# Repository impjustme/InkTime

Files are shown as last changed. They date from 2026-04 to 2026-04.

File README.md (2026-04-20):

# InkTime

InkTime este un smartwatch open-source cu consum redus, construit in jurul microcontroller-ului nRF52840, cu ecran e-paper, alimentare din baterie Li-Po, incarcare prin USB-C, monitorizare baterie, IMU si feedback haptic. Platforma a fost proiectata pentru autonomie buna, dimensiuni compacte si integrare mecanica intr-o carcasa dedicata.

## Diagrama bloc

```
                                +----------------------+
                                |       USB-C          |
                                |   alimentare / USB   |
                                +----------+-----------+
                                           |
                                           v
                                +----------------------+
                                |   ESD Protection     |
                                |    USBLC6-2SC6Y      |
                                +----------+-----------+
                                           |
                                           v
                                +----------------------+
                                |  Li-Po Charger       |
                                |    BQ25180YBGR       |
                                +----+------------+----+
                                     |            |
                                     |            +--------------------+
                                     |                                 |
                                     v                                 v
                           +-------------------+             +-------------------+
                           |    Li-Po Battery  |             |   Fuel Gauge      |
                           |     LP502030      |<-- I2C ---> |    MAX17048       |
                           +---------+---------+             +-------------------+
                                     |
                                     v
                           +-------------------+
                           |  Buck-Boost DC/DC |
                           |    RT6160AWSC     |
                           +---------+---------+
                                     |
                                   3V3/VREG
                                     |
        +----------------------------+------------------------------+
        |                            |                              |
        v                            v                              v
+---------------+          +-------------------+          +-------------------+
|   nRF52840    |<--I2C--->|      BMA423       |<--I2C--->|     DRV2605       |
| BLE MCU       |          |       IMU         |          |   Haptic Driver   |
+-------+-------+          +-------------------+          +---------+---------+
        |                                                              |
        | SPI + GPIO                                                    v
        v                                                      +----------------+
+-------------------+                                          | Vibration Motor |
| 1.54" E-Paper     |                                          |    10 x 2.7 mm  |
| via FPC connector |                                          +----------------+
+-------------------+
        |
        +--> boost / gate drive pentru EPD:
             MOSFET-uri + diode Schottky + inductoare + condensatori
```

## BoM

| Componenta | Part number / Valoare  | Rol | Link JLC / sursa | Datasheet |
| --- | --- | --- | --- | --- |
| MCU | nRF52840 | microcontroller principal BLE | JLC Parts / external sourcing | [https://infocenter.nordicsemi.com/pdf/nRF52840_PS_v1.1.pdf](https://infocenter.nordicsemi.com/pdf/nRF52840_PS_v1.1.pdf) |
| PMIC charger | BQ25180YBGR | incarcare Li-Po prin USB-C | JLC Parts | [https://www.ti.com/lit/ds/symlink/bq25180.pdf](https://www.ti.com/lit/ds/symlink/bq25180.pdf) |
| DC/DC | RT6160AWSC | conversie VBAT -> 3V3/VREG | JLC Parts / external sourcing | [https://www.richtek.com/assets/product_file/RT6160A/DS6160A-05.pdf](https://www.richtek.com/assets/product_file/RT6160A/DS6160A-05.pdf) |
| Fuel gauge | MAX17048G+T10 | monitorizare baterie | JLC Parts / external sourcing | [https://www.analog.com/media/en/technical-documentation/data-sheets/max17048-max17049.pdf](https://www.analog.com/media/en/technical-documentation/data-sheets/max17048-max17049.pdf) |
| IMU | BMA423 | accelerometru triaxial | JLC Parts / external sourcing | [https://www.bosch-sensortec.com/products/motion-sensors/accelerometers/bma423/](https://www.bosch-sensortec.com/products/motion-sensors/accelerometers/bma423/) |
| Haptic driver | DRV2605YZFR | comanda motorului de vibratie | JLC Parts / external sourcing | [https://www.ti.com/lit/ds/symlink/drv2605.pdf](https://www.ti.com/lit/ds/symlink/drv2605.pdf) |
| ESD USB | USBLC6-2SC6Y | protectie ESD pentru USB | JLC Parts | [https://www.st.com/resource/en/datasheet/usblc6-2.pdf](https://www.st.com/resource/en/datasheet/usblc6-2.pdf) |
| Antena | 2450AT18B100E | antena 2.4 GHz | external sourcing | [https://www.johansontechnology.com/datasheets/antennas/2450AT18B100.pdf](https://www.johansontechnology.com/datasheets/antennas/2450AT18B100.pdf) |
| Conector debug | TC2030-IDC | SWD / debugging | external sourcing | [https://www.tag-connect.com/product/tc2030-idc](https://www.tag-connect.com/product/tc2030-idc) |
| Conector display | 503480-2400 | conector FPC pentru e-paper | external sourcing | [https://www.molex.com/en-us/products/part-detail/5034802400](https://www.molex.com/en-us/products/part-detail/5034802400) |
| USB-C | KH-TYPE-C-16P | alimentare si interfata USB | JLC Parts / external sourcing | |
| Cristal HF | 32 MHz, SMD 2016 | ceas principal MCU | JLC Parts / external sourcing | |
| Cristal LF | 32.768 kHz, SMD 3215 | RTC / low-power clock | JLC Parts / external sourcing | |
| MOSFET EPD | SI1308EDL-T1-GE3 | comanda in etajul e-paper | JLC Parts / external sourcing | [https://www.vishay.com/docs/68986/si1308edl.pdf](https://www.vishay.com/docs/68986/si1308edl.pdf) |
| MOSFET EPD | DMG2305UX-7 / echiv. | comanda in etajul e-paper | JLC Parts / external sourcing | [https://www.diodes.com/assets/Datasheets/DMG2305UX.pdf](https://www.diodes.com/assets/Datasheets/DMG2305UX.pdf) |
| Diode Schottky | MBR0530 | etaj boost / redresare EPD | JLC Parts / external sourcing | [https://www.onsemi.com/pdf/datasheet/mbr0530t1-d.pdf](https://www.onsemi.com/pdf/datasheet/mbr0530t1-d.pdf) |
| Inductor power | FTC252012SR47MBCA | inductor pentru RT6160 | JLC Parts | [https://jlcpcb.com/partdetail/6763488-FTC252012SR47MBCA/C5832368](https://jlcpcb.com/partdetail/6763488-FTC252012SR47MBCA/C5832368) |
| Inductor EPD | 68uH | inductor pentru boost EPD | JLC Parts / external sourcing | |
| Butoane | EVP-AKE31A | interfata utilizator | JLC Parts / external sourcing | |
| Baterie | LP502030, 3.7V, 250mAh | sursa principala de energie | external sourcing | |
| Display | 1.54" e-paper, 200x200 | afisaj principal | external sourcing | |
| Shaker | 10 x 2.7 mm | vibratie / feedback haptic | external sourcing | |
## Descriere hardware
1. Microcontroller principal

Sistemul este construit in jurul nRF52840, un microcontroller ARM Cortex-M4F cu BLE 5.x, suficient de performant pentru gestionarea afisajului e-paper, a senzorilor, a starii de baterie si a interfetei de utilizator.Pe partea de clock sunt folosite doua surse:

-un cristal de 32 MHz pentru clock-ul principal.

-un cristal de 32.768 kHz pentru RTC si scenarii low-power.

2. Alimentare si management energetic

Arhitectura de alimentare este impartita in trei blocuri.

BQ25180YBGR

Gestioneaza incarcarea bateriei Li-Po din USB-C. Intrarea de 5 V vine din VBUS, iar iesirea este conectata la bateria de o celula. Acest circuit este configurabil si monitorizabil, iar pinul de interrupt este dus catre MCU.

MAX17048

Monitorizeaza tensiunea si starea bateriei. Acesta comunica pe I2C cu microcontrollerul si expune un semnal de alerta pentru praguri critice sau schimbari de stare.

RT6160AWSC

Converteaza tensiunea bateriei intr-o alimentare stabila pentru sistemul digital. Acesta este blocul care alimenteaza rail-urile de lucru ale placii si perifericele sale.

In proiect, bateria nu este conectata printr-un conector JST clasic, ci direct la doua test pad-uri dedicate de pe PCB, una pentru VBAT si una pentru GND, pentru economie de spatiu.

3. Afisaj

Afisajul utilizat este un e-paper de 1.54", conectat printr-un conector FPC. Comunicatia cu MCU se face in principal prin SPI, iar pentru control sunt folosite si semnale GPIO dedicate:

CS

DC

RST

BUSY

Deoarece e-paper-ul necesita tensiuni si secvente specifice, exista un etaj discret dedicat pentru generarea si comutarea semnalelor de alimentare ale panelului, construit cu:

MOSFET-uri

diode Schottky

inductoare

condensatori de filtrare si bootstrap

4. IMU

BMA423 este accelerometrul triaxial folosit pentru detectie de miscare, pasi, gesturi si evenimente de trezire. Comunicatia se face pe I2C, iar semnalele de intrerupere sunt aduse pe GPIO-uri separate ale MCU-ului pentru reactii rapide si trezire din moduri low-power.

5. Feedback haptic

DRV2605 comanda un motor de vibratie compact. Comunicatia cu MCU se face pe I2C, iar activarea poate fi controlata si printr-un semnal GPIO dedicat. Acest bloc ofera feedback tactil pentru navigare, notificari si interactiuni de baza.

6. USB-C si protectie

Interfata USB-C este folosita pentru alimentare si, optional, interfata USB a microcontrollerului. Liniile sensibile sunt protejate cu USBLC6-2SC6Y. Liniile CC sunt terminate corespunzator pentru a permite functionarea corecta ca device.

7. RF si antena

Conectivitatea radio este realizata prin antena chip 2.4 GHz si o retea de matching RF. Antena este pozitionata la marginea PCB-ului, iar sub ea exista zona de keepout fara trasee si fara plan de masa, pentru a nu degrada performanta RF.

## Pini folositi

| Pin nRF52840  | Semnal | Destinatie | Motiv |
| --- | --- | --- | --- |
| P0.00 / XL1 | XL1 | cristal 32.768 kHz | clock low-power / RTC |
| P0.01 / XL2 | XL2 | cristal 32.768 kHz | clock low-power / RTC |
| P0.04 | IMU_INT1 | BMA423 | intrerupere senzor |
| P0.05 | IMU_INT2 | BMA423 | intrerupere senzor |
| P0.06 | EPD_CS | e-paper | selectie SPI display |
| P0.07 | EPD_DC | e-paper | selectie data/comanda |
| P0.08 | EPD_RST | e-paper | reset display |
| P0.09 | PMIC_INT | BQ25180 | interrupt charger / PMIC |
| P0.11 | SPI_SCK | e-paper | clock SPI |
| P0.12 | SPI_MOSI | e-paper | date SPI |
| P0.13 | EPD_BUSY | e-paper | busy status display |
| P0.14 | I2C_SCL | BMA423 / DRV2605 / MAX17048 / BQ25180 / RT6160 | magistrala I2C comuna |
| P0.15 | I2C_SDA | BMA423 / DRV2605 / MAX17048 / BQ25180 / RT6160 | magistrala I2C comuna |
| P0.18 / RESET | RESET | sistem | reset hardware |
| P0.19 | HAPTIC_EN | DRV2605 | enable local pentru blocul haptic |
| P0.26 | SW_UP | buton | input utilizator |
| P0.27 | SW_DN | buton | input utilizator |
| P1.00 | SW_ENT | buton | input utilizator |
| P1.01 | ALERT | MAX17048 | alerta fuel gauge |
| P1.09 | SWO | debug | trace / debugging |
| XC1 / XC2 | 32 MHz crystal | clock principal | stabilitate si RF |
| ANT | RF | antena + matching | transmisie radio BLE |
| SWDIO | debug | TC2030-IDC | programare / debug |
| SWDCLK | debug | TC2030-IDC | programare / debug |
| VBUS | alimentare USB | USB-C | intrare 5 V |
| D+ / D- | USB data | USB-C prin protectie ESD | interfata USB |

## PCB

Layer stack

Structura folosita:

Top - componente, rutare semnale, poligoane GND locale

Route2 - plan principal de masa / referinta

Route15 - rutare interna suplimentara pentru semnale si distributie

Bottom - rutare suplimentara si zone GND

## Design log

In procesul de layout au fost acceptate:

1. SMD - via / pin overlap

In zone foarte dense, in special langa capsule mici si in fanout-ul unor componente fine-pitch, anumite vias au fost plasate direct pe pini ai componentelor.

3. Copper width warnings

Pe rail-urile de putere s-a urmarit 0.3 mm acolo unde spatiul permite. In fanout-uri foarte scurte, imediat la iesirea din pini foarte mici sau intre componente apropiate, au ramas segmente locale mai inguste. Distributia principala de putere a fost mentinuta lata, iar exceptiile sunt limitate la zonele de iesire.

4. Board outline / edge related warnings

Elementele de interfata ale produsului, in special anumite butoane si zona conectorului, au fost aliniate mecanic cu produsul final. Acolo unde apar avertizari de proximitate fata de conturul placii, acestea au fost evaluate din punct de vedere mecanic si acceptate daca nu afecteaza functionalitatea.

5. Unghiuri drepte locale
   
Desi rutarea a fost facuta preponderent fara colturi de 90 de grade, au ramas cateva unghiuri drepte locale in zone foarte aglomerate. Acestea au fost mentinute doar acolo unde alternativele cresteau numarul de vias sau complicau excesiv rutarea.

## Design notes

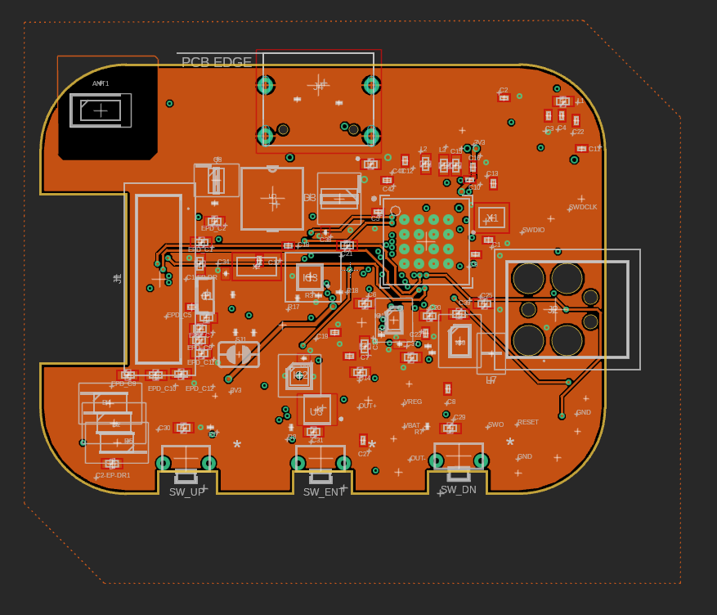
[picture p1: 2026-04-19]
Images/r15.png

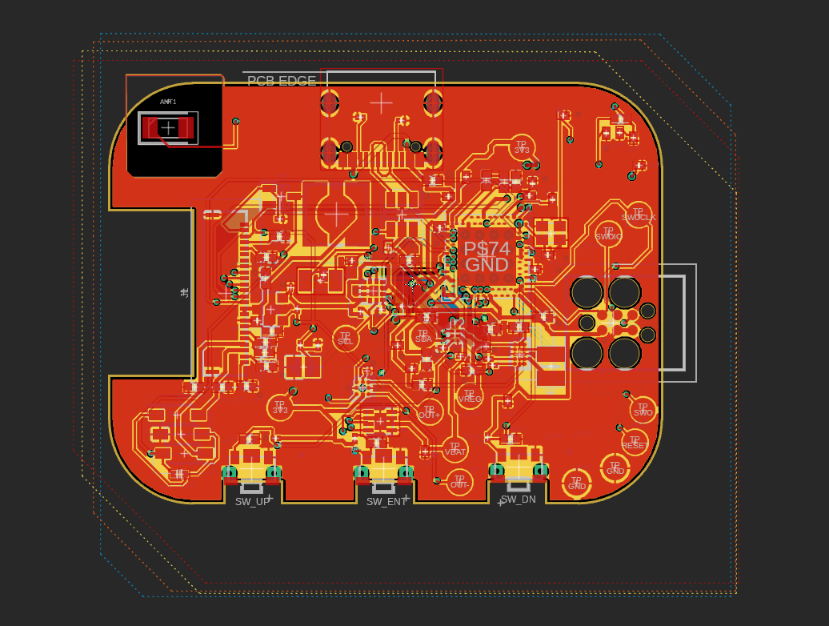
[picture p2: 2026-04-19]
Images/all_layers.png

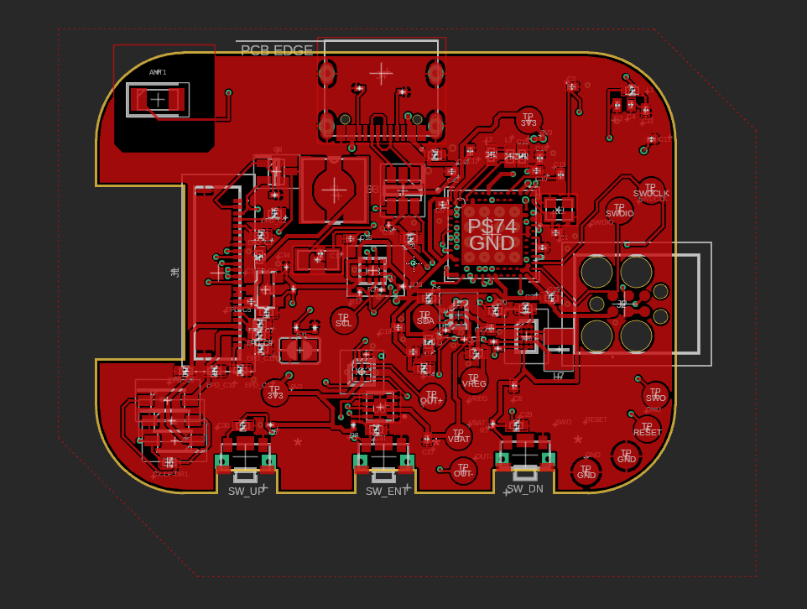
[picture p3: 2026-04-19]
Images/top.png

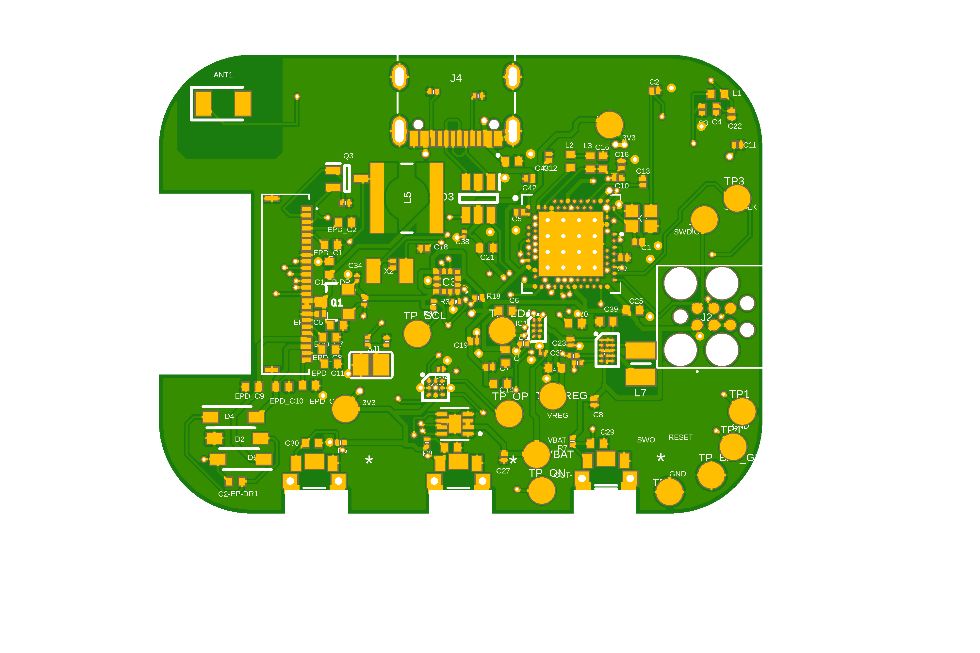
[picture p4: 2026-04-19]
Images/InkTime_cam_preview.png

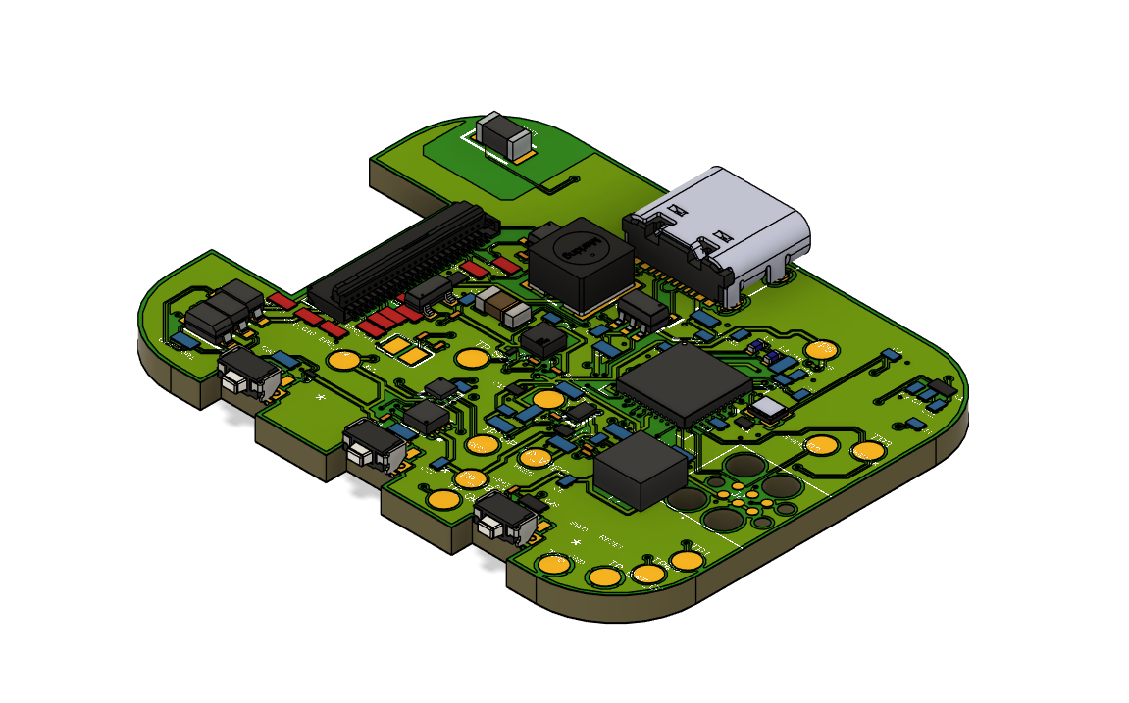
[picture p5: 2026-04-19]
Images/side_3D.png

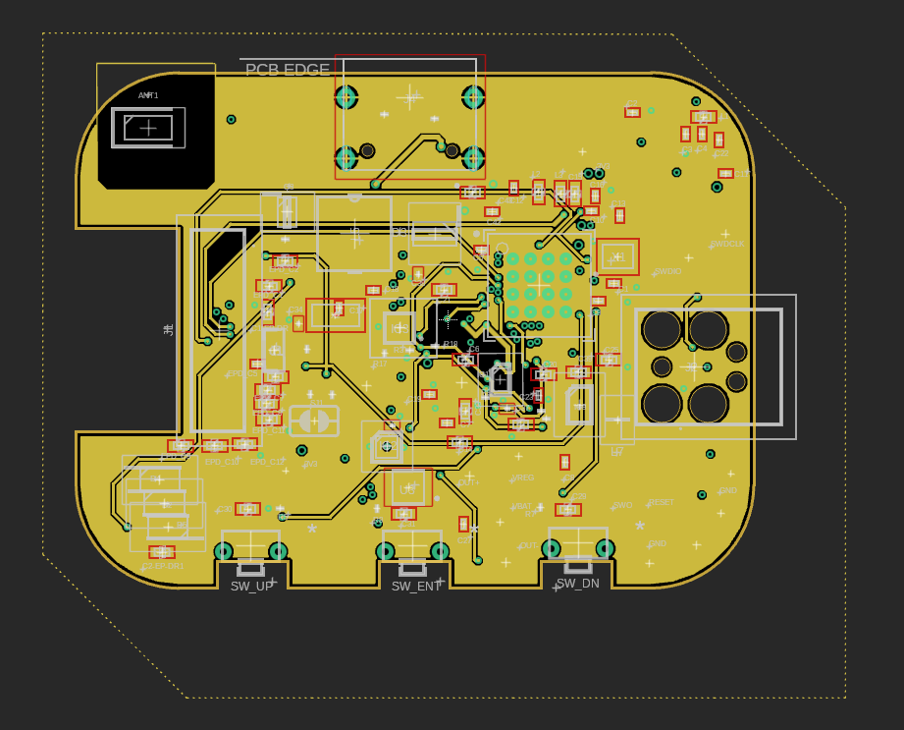
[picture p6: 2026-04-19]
Images/r2.png

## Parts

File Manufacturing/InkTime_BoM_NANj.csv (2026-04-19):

Qty | Value | Device | Package | Parts | Description | ARROW_PART_NUMBER | ARROW_PRICE-STOCK | AVAILABILITY | CHECK_PRICES | COPYRIGHT | DESCRIPTION | DIGI-KEY_PART_NUMBER_1 | DIGI-KEY_PART_NUMBER_2 | DIGI-KEY_PART_NUMBER_3 | HEIGHT | JLCPCB | MANUFACTURER_NAME | MANUFACTURER_PART_NUMBER | MF | MFR_NAME | MOUSER_PART_NUMBER | MOUSER_PRICE-STOCK | MP | PACKAGE | POPULARITY | PRICE | PROD_ID | PURCHASE-URL | SNAPEDA_LINK | TP_SIGNAL_NAME | VALUE
1 |  | ESP32_C6_LIBRARY_7_JUMPER_SJ | ESP32_C6_LIBRARY_7_JUMPER_SJ | SJ1 | SMD solder JUMPER |  |  |  |  |  |  |  |  |  |  |  |  |  |  |  |  |  |  |  | 3
2 |  | NORDIC_NRF_3_CAPACITOR_0201_L | NORDIC_NRF_3_RESC0201_L | C10, C13 | Generic chip capacitor
1 | 0.1uF | GRM011R60J152KE01L_2_GRM011R60J152KE01L | GRM011R60J152KE01L_2_CAPC0201X13N | C34 | Check availability |  |  | In Stock | https://www.snapeda.com/parts/GRM011R60J152KE01L/Murata/view-part/?ref=eda |  | SMD Capacitor X5R(EIA) with Capacitance: 1500pF Tol. 10%. Rated Voltage: 6.3Vdc |  |  |  |  |  |  |  | Murata |  |  |  | GRM011R60J152KE01L | 0201 Murata |  | None |  |  | https://www.snapeda.com/parts/GRM011R60J152KE01L/Murata/view-part/?ref=snap
3 | 0.1uF | NORDIC_NRF_3_CAPACITOR_0201_L | NORDIC_NRF_3_RESC0201_L | C23, C27, C42 | Generic chip capacitor
1 | 0.1uF/50V | NORDIC_NRF_3_CAPACITOR_0201_L | NORDIC_NRF_3_RESC0201_L | EPD_C5 | Generic chip capacitor
1 | 0.47 | CPF0201D7K68C1_CPF0201D7K68C1 | CPF0201D7K68C1_0201 | R1_EP_DR | 7.68k 0201 Thin Film Surface Mount Fixed Resistor +/-0.5% 0.031W CPF0201D7K68C1
1 | 1.0µF | NORDIC_NRF_3_CAPACITOR_0402_L | NORDIC_NRF_3_RESC0402_L | C15 | Generic chip capacitor
5 | 100nF | NORDIC_NRF_3_CAPACITOR_0201_L | NORDIC_NRF_3_RESC0201_L | C5, C7, C8, C12, C19 | Generic chip capacitor
1 | 100pF | NORDIC_NRF_3_CAPACITOR_0201_L | NORDIC_NRF_3_RESC0201_L | C11 | Generic chip capacitor
3 | 10K | CPF0201D7K68C1_CPF0201D7K68C1 | CPF0201D7K68C1_0201 | R2_EP_DR, R9, R_PWR_EPD | 7.68k 0201 Thin Film Surface Mount Fixed Resistor +/-0.5% 0.031W CPF0201D7K68C1
3 | 10k | CPF0201D7K68C1_CPF0201D7K68C1 | CPF0201D7K68C1_0201 | R5, R7, R8 | 7.68k 0201 Thin Film Surface Mount Fixed Resistor +/-0.5% 0.031W CPF0201D7K68C1
3 | 10uF | NORDIC_NRF_3_CAPACITOR_0402_L | NORDIC_NRF_3_RESC0402_L | C1-EP-DR, C24, C39 | Generic chip capacitor
1 | 10µH | NORDIC_NRF_2_INDUCTOR_0402_L | NORDIC_NRF_2_RESC0402_L | L2 | Generic chip inductor
4 | 12pF | NORDIC_NRF_3_CAPACITOR_0201_L | NORDIC_NRF_3_RESC0201_L | C1, C2, C17, C18 | Generic chip capacitor
1 | 15nF | NORDIC_NRF_2_INDUCTOR_0402_L | NORDIC_NRF_2_RESC0402_L | L3 | Generic chip inductor
2 | 1pF | NORDIC_NRF_3_CAPACITOR_0201_L | NORDIC_NRF_3_RESC0201_L | C3, C4 | Generic chip capacitor
3 | 1uF | GRM011R60J152KE01L_2_GRM011R60J152KE01L | GRM011R60J152KE01L_2_CAPC0201X13N | C32, C37, C38 | Check availability |  |  | In Stock | https://www.snapeda.com/parts/GRM011R60J152KE01L/Murata/view-part/?ref=eda |  | SMD Capacitor X5R(EIA) with Capacitance: 1500pF Tol. 10%. Rated Voltage: 6.3Vdc |  |  |  |  |  |  |  | Murata |  |  |  | GRM011R60J152KE01L | 0201 Murata |  | None |  |  | https://www.snapeda.com/parts/GRM011R60J152KE01L/Murata/view-part/?ref=snap
3 | 1uF | NORDIC_NRF_3_CAPACITOR_0402_L | NORDIC_NRF_3_RESC0402_L | C29, C30, C31 | Generic chip capacitor
9 | 1uF/50V | NORDIC_NRF_3_CAPACITOR_0402_L | NORDIC_NRF_3_RESC0402_L | EPD_C1, EPD_C2, EPD_C6, EPD_C7, EPD_C8, EPD_C9, EPD_C10, EPD_C11, EPD_C12 | Generic chip capacitor
1 | 2.2 | CPF0201D7K68C1_CPF0201D7K68C1 | CPF0201D7K68C1_0201 | R_TYPE_SEL | 7.68k 0201 Thin Film Surface Mount Fixed Resistor +/-0.5% 0.031W CPF0201D7K68C1
2 | 2025-10-22_07-23-44_LIBRARY_EVP-AKE31ASW_EVP-AKE31A_PAN | 2025-10-22_07-23-44_LIBRARY_EVP-AKE31ASW_EVP-AKE31A_PAN | 2025-10-22_07-23-44_LIBRARY_SW_EVP-AKE31A_PAN | SW_DN, SW_UP |  |  |  |  |  | Copyright (C) 2025 Ultra Librarian. All rights reserved. |  | P123437TR-ND | P123437CT-ND | P123437DKR-ND |  |  | Panasonic | EVP-AKE31A
1 | 20V/4.2A/52mO/1.4W | ESP32_C6_LIBRARY_4_ESP32_WROVER_SPARKFUN-DISCRETESEMI_MOSFET_PCH-DMG2305UX-7 | ESP32_C6_LIBRARY_4_ESP32_C6_LIBRARY_4_ESP32_C6_LIBRARY_4_ESP32_C6_LIBRARY_4_ESP32_WROVER_SPARKFUN-DISCRETESEMI_SOT23-3 | Q1 | P-channel MOSFETs |  |  |  |  |  |  |  |  |  |  |  |  |  |  |  |  |  |  |  |  |  | TRAN-14388 |  |  |  | 20V/4.2A/52mO/1.4W
2 | 22uF | NORDIC_NRF_3_CAPACITOR_0402_L | NORDIC_NRF_3_RESC0402_L | C25, C33 | Generic chip capacitor
1 | 2450AT18B100E | 2450AT18B100E_2450AT18B100E | 2450AT18B100E_ANTC3216X140N | ANT1 | Antennas 2.45GHz ANTENNA | 2450AT18B100E | https://www.arrow.com/en/products/2450at18b100e/johanson-dielectrics?utm_currency=USD&region=nac |  |  |  | Antennas 2.45GHz ANTENNA |  |  |  | 1.4mm |  | JOHANSON TECHNOLOGY | 2450AT18B100E |  |  | 609-2450AT18B100E | https://www.mouser.co.uk/ProductDetail/Johanson-Technology/2450AT18B100E?qs=yCnrNFeXz%252Bh5MFsFIXGZGA%3D%3D
1 | 3.9nH | NORDIC_NRF_2_INDUCTOR_0402_L | NORDIC_NRF_2_RESC0402_L | L1 | Generic chip inductor
1 | 32.768kHz | NORDIC_NRF_1_XTAL_32KHZ | NORDIC_NRF_1_XTAL_3215_N | X2
1 | 32MHz | NORDIC_NRF_XTAL_32MHZ | NORDIC_NRF_BT-XTAL_2016_N | X1
2 | 3K3 | CPF0201D7K68C1_CPF0201D7K68C1 | CPF0201D7K68C1_0201 | R17, R18 | 7.68k 0201 Thin Film Surface Mount Fixed Resistor +/-0.5% 0.031W CPF0201D7K68C1
1 | 4.7uF | NORDIC_NRF_3_CAPACITOR_0402_L | NORDIC_NRF_3_RESC0402_L | C43 | Generic chip capacitor
1 | 4.7uF/25V | NORDIC_NRF_3_CAPACITOR_0402_L | NORDIC_NRF_3_RESC0402_L | C2-EP-DR1 | Generic chip capacitor
4 | 4.7µF | NORDIC_NRF_3_CAPACITOR_0402_L | NORDIC_NRF_3_RESC0402_L | C6, C14, C20, C21 | Generic chip capacitor
1 | 47nF | NORDIC_NRF_3_CAPACITOR_0201_L | NORDIC_NRF_3_RESC0201_L | C16 | Generic chip capacitor
1 | 503480-2400 | 503480-2400_503480-2400 | 503480-2400_5034802400 | J1 | FFC & FPC Connectors 0.5mm FPC RA SMT Dual Contact 24Ckt |  |  |  |  |  | FFC & FPC Connectors 0.5mm FPC RA SMT Dual Contact 24Ckt |  |  |  | 1.87mm |  | Molex | 503480-2400 |  |  | 538-503480-2400 | https://www.mouser.co.uk/ProductDetail/Molex/503480-2400?qs=OAhjpuo3Vu7efIoxFh9AOw%3D%3D
2 | 5K1 | ERA-1AEB3401C_CPF0201D7K68C1 | ERA-1AEB3401C_0201 | R1_USB, R2_USB | 7.68k 0201 Thin Film Surface Mount Fixed Resistor +/-0.5% 0.031W CPF0201D7K68C1
1 | 68uH | ESP32_C6_LIBRARY_2_744043680IND_4828-WE-TPC_WRE | ESP32_C6_LIBRARY_2_IND_4828-WE-TPC_WRE | L5 |  |  |  |  |  | Copyright (C) 2024 Ultra Librarian. All rights reserved. |  |  |  |  |  |  |  | 744043680 |  | Wurth Electronics
1 | 820pF | NORDIC_NRF_3_CAPACITOR_0201_L | NORDIC_NRF_3_RESC0201_L | C9 | Generic chip capacitor
1 | BMA423 | BMA423_BMA423 | BMA423_BMA423 | IC3 | Accelerometers Triaxial low-g 12bit Acceleration Sensor | BMA423 | https://www.arrow.com/en/products/bma423/bosch |  |  |  | Accelerometers Triaxial low-g 12bit Acceleration Sensor |  |  |  | 1mm |  | BOSCH | BMA423 |  |  | 262-BMA423 | https://www.mouser.co.uk/ProductDetail/Bosch-Sensortec/BMA423?qs=HXFqYaX1Q2xC%252BSgeGoX3mg%3D%3D
1 | BQ25180YBGR | BQ25180YBGR_BQ25180YBGR | BQ25180YBGR_BGA8C40P2X4_100X155X50 | IC1 | Charger IC Lithium Ion/Polymer, Lithium Iron Phosphate 8-DSBGA (1.6x1.1) | BQ25180YBGR | https://www.arrow.com/en/products/bq25180ybgr/texas-instruments?utm_currency=USD&region=nac |  |  |  | Charger IC Lithium Ion/Polymer | Lithium Iron Phosphate 8-DSBGA (1.6x1.1) |  |  |  | 0.5mm |  | Texas Instruments | BQ25180YBGR |  |  | 595-BQ25180YBGR | https://www.mouser.co.uk/ProductDetail/Texas-Instruments/BQ25180YBGR?qs=doiCPypUmgEWjAK%252BJAX6Tw%3D%3D
3 | CPF0201D7K68C1_CPF0201D7K68C1 | CPF0201D7K68C1_CPF0201D7K68C1 | CPF0201D7K68C1_0201 | R2, R3, R4 | 7.68k 0201 Thin Film Surface Mount Fixed Resistor +/-0.5% 0.031W CPF0201D7K68C1
1 | DRV2605YZFR | DRV2605YZFR_DRV2605YZFR | DRV2605YZFR_BGA9C50P3X3_144X144X62 | IC2 | Haptic Driver for ERM/LRA with Built-In Library and Smart Loop Architecture | DRV2605YZFR | https://www.arrow.com/en/products/drv2605yzfr/texas-instruments?region=nac |  |  |  | Haptic Driver for ERM/LRA with Built-In Library and Smart Loop Architecture |  |  |  | 0.625mm |  | Texas Instruments | DRV2605YZFR
1 | FTC252012SR47MBCA | MLP2016SR47MT0S1_FTC252012SR47MBCA | MLP2016SR47MT0S1_INDC2016X100N | L7 | SMD / SMT Inductors (Coils), L=0.47?H, L x W x T : |  |  |  |  |  | SMD / SMT Inductors (Coils) | L=0.47?H | L x W x T : |  |  |  | 1mm | https://jlcpcb.com/partdetail/6763488-FTC252012SR47MBCA/C5832368 | TDK | FTC252012SR47MBCA
14 | HECTOR_WATCH_1_TPTP20R | HECTOR_WATCH_1_TPTP20R | HECTOR_WATCH_1_TP20R | TP1, TP2, TP3, TP4, TP5, TP6, TP_3V3, TP_BAT_GND, TP_ON, TP_OP, TP_SCL, TP_SDA, TP_VBAT, TP_VREG | Test pad |  |  |  |  |  |  |  |  |  |  |  |  |  |  |  |  |  |  |  | 2
1 | KH-TYPE-C-16P | KH-TYPE-C-16P_KH-TYPE-C-16P | KH-TYPE-C-16P_KINGHELM_KH-TYPE-C-16P | J4 | Check availability |  |  | Not in stock | https://www.snapeda.com/parts/KH-TYPE-C-16P/Kinghelm/view-part/?ref=eda |  |  |  |  |  |  |  |  |  | kinghelm |  |  |  | KH-TYPE-C-16P | None |  | None |  |  | https://www.snapeda.com/parts/KH-TYPE-C-16P/Kinghelm/view-part/?ref=snap
1 | MAX17048G+T10 | ESP32_C6_LIBRARY_MAX17048G+T10 | ESP32_C6_LIBRARY_SON50P200X200X80-9N | U3 | Check availability |  |  | In Stock | https://www.snapeda.com/parts/MAX17048G+T10/Analog+Devices/view-part/?ref=eda |  | 3µA 1-Cell/2-Cell Fuel Gauge with ModelGauge |  |  |  |  |  |  |  | Analog Devices |  |  |  | MAX17048G+T10 | TDFN-8 Maxim |  | None |  | https://www.snapeda.com/api/url_track_click_mouser/?unipart_id=329239&manufacturer=Analog Devices&part_name=MAX17048G+T10&search_term=None | https://www.snapeda.com/parts/MAX17048G+T10/Analog+Devices/view-part/?ref=snap
3 | MBR0530 | ESP32_C6_LIBRARY_5_MBR0530 | ESP32_C6_LIBRARY_5_SOD3716X135N | D2, D4, D5 | ON SEMICONDUCTOR - MBR0530 - DIODE, SCHOTTKY, 0.5A, 30V, SOD-123 |  |  | In Stock | https://www.snapeda.com/parts/MBR0530/Onsemi/view-part/?ref=eda |  | Diode Schottky 30 V 500mA Surface Mount SOD-123 |  |  |  |  |  |  |  | ON Semiconductor |  |  |  | MBR0530 | SOD-123-2 ON Semiconductor |  | None |  | https://www.snapeda.com/api/url_track_click_mouser/?unipart_id=179458&manufacturer=ON Semiconductor&part_name=MBR0530&search_term=None | https://www.snapeda.com/parts/MBR0530/Onsemi/view-part/?ref=snap
1 | N.C. | NORDIC_NRF_3_CAPACITOR_0201_L | NORDIC_NRF_3_RESC0201_L | C22 | Generic chip capacitor
1 | NRF52840_QF | NORDIC_NRF_4_NRF52840_QF | NORDIC_NRF_4_AQFN50P700X700X85_HS-74N | U1 | nRF52840
1 | RT6160AWSC | RT6160AWSC_RT6160AWSC | RT6160AWSC_BGA15C40P3X5_140X230X60 | IC9 | Buck-Boost Regulator Positive Output Step-Up/Step-Down I2C DC-DC Controller IC 15-WL-CSP (BSC) (1.4x2.3) |  |  |  |  |  | Buck-Boost Regulator Positive Output Step-Up/Step-Down I2C DC-DC Controller IC 15-WL-CSP (BSC) (1.4x2.3) |  |  |  | 0.6mm |  | RICHTEK | RT6160AWSC |  |  | 835-RT6160AWSC | https://www.mouser.co.uk/ProductDetail/Richtek/RT6160AWSC?qs=amGC7iS6iy%2FLd9PSoixZXQ%3D%3D
1 | SI1308EDL-T1-GE3 | ESP32_C6_LIBRARY_6_SI1308EDL-T1-GE3 | ESP32_C6_LIBRARY_6_SOT65P210X110-3N | Q3 | MOSFET N-Ch 30V 1.5A TrenchFET SC70 Vishay Si1308EDL-T1-GE3 N-channel MOSFET Transistor, 1.5 A, 30 V, 3-Pin SC-70 |  |  | In Stock | https://www.snapeda.com/parts/SI1308EDL-T1-GE3/Vishay+Siliconix/view-part/?ref=eda |  | Si1308EDL-T1-GE3 N-channel MOSFET Transistor | 1.5 A | 30 V | 3-Pin SC-70 | Siliconix / Vishay SI1308EDL-T1-GE3 |  |  |  |  |  |  |  | Vishay Siliconix |  |  |  | SI1308EDL-T1-GE3 | SOT-323 Vishay Semiconductor |  | None |  | https://www.snapeda.com/api/url_track_click_mouser/?unipart_id=274603&manufacturer=Vishay Siliconix&part_name=SI1308EDL-T1-GE3&search_term=None
1 | SW_ENT | 2025-10-22_07-23-44_LIBRARY_EVP-AKE31ASW_EVP-AKE31A_PAN | 2025-10-22_07-23-44_LIBRARY_SW_EVP-AKE31A_PAN | SW_ENT |  |  |  |  |  | Copyright (C) 2025 Ultra Librarian. All rights reserved. |  | P123437TR-ND | P123437CT-ND | P123437DKR-ND |  |  | Panasonic | EVP-AKE31A
1 | TC2030-IDC | TC2030-IDC_TC2030-IDC | TC2030-IDC_TC2030IDC | J2 | CABLE ADAPTER 6 POS |  |  |  |  |  | CABLE ADAPTER 6 POS |  |  |  | 19mm |  | Tag Connect | TC2030-IDC
1 | USBLC6-2SC6Y | ESP32_C6_LIBRARY_3_USBLC6-2SC6Y | ESP32_C6_LIBRARY_3_SOT95P280X145-6N | D3 | Low Cap. ESD Protection Auto SOT-23-6 STMicroelectronics USBLC6-2SC6Y, Dual Uni-Directional TVS Diode Array, 6-Pin SOT-23 |  |  | In Stock | https://www.snapeda.com/parts/USBLC6-2SC6Y/STMicroelectronics/view-part/?ref=eda |  | 17V Clamp 5A (8/20µs) Ipp Tvs Diode Surface Mount SOT-23-6 |  |  |  |  |  |  |  | STMicroelectronics |  |  |  | USBLC6-2SC6Y | SOT-23-6 STMicroelectronics |  | None |  |  | https://www.snapeda.com/parts/USBLC6-2SC6Y/STMicroelectronics/view-part/?ref=snap

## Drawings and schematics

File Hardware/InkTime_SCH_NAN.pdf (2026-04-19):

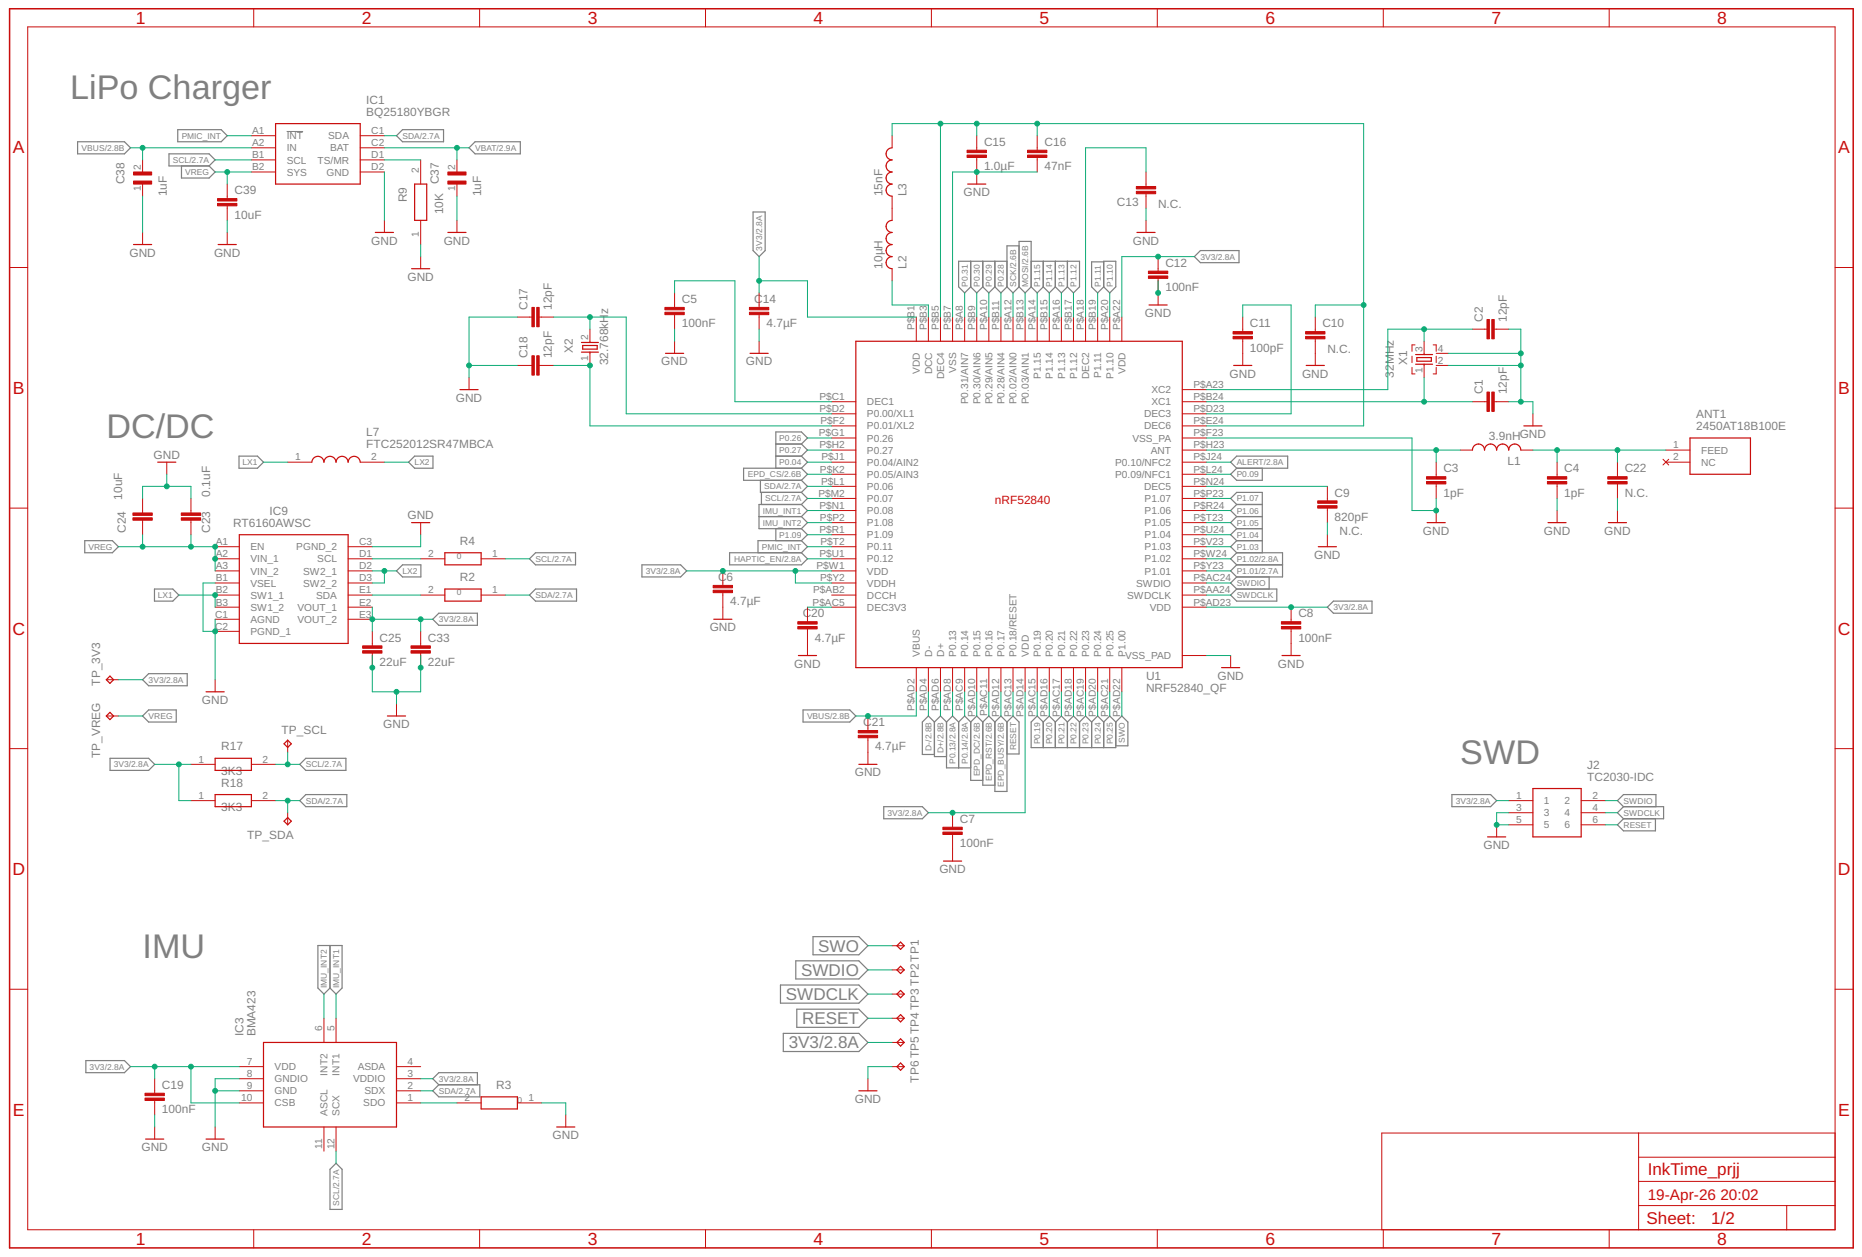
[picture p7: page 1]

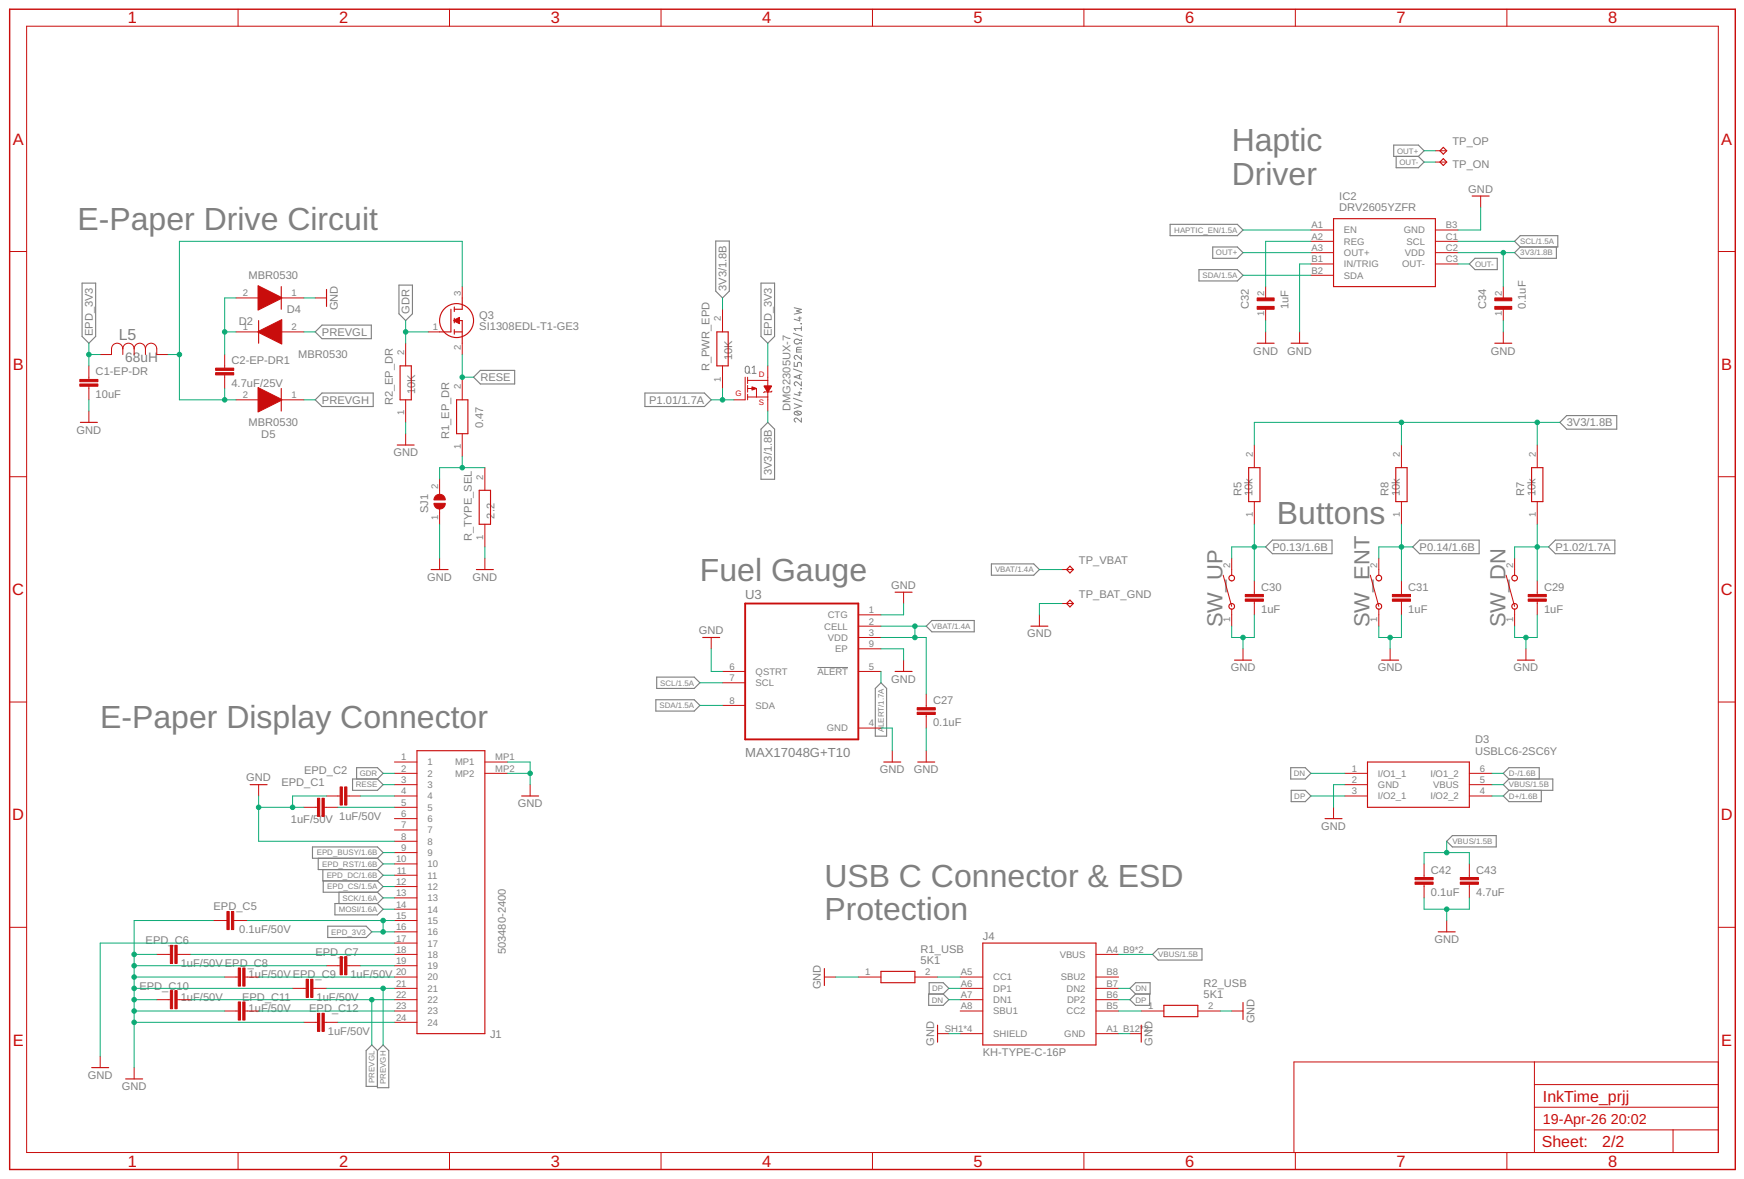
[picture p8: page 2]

EPD_C10 | | 21

1uF/50V EPD_C9 | 1uF/50V 20

1uF/50V EPD_C11 | 1uF/50V | 22

1uF/50V EPD_C12 | | 23

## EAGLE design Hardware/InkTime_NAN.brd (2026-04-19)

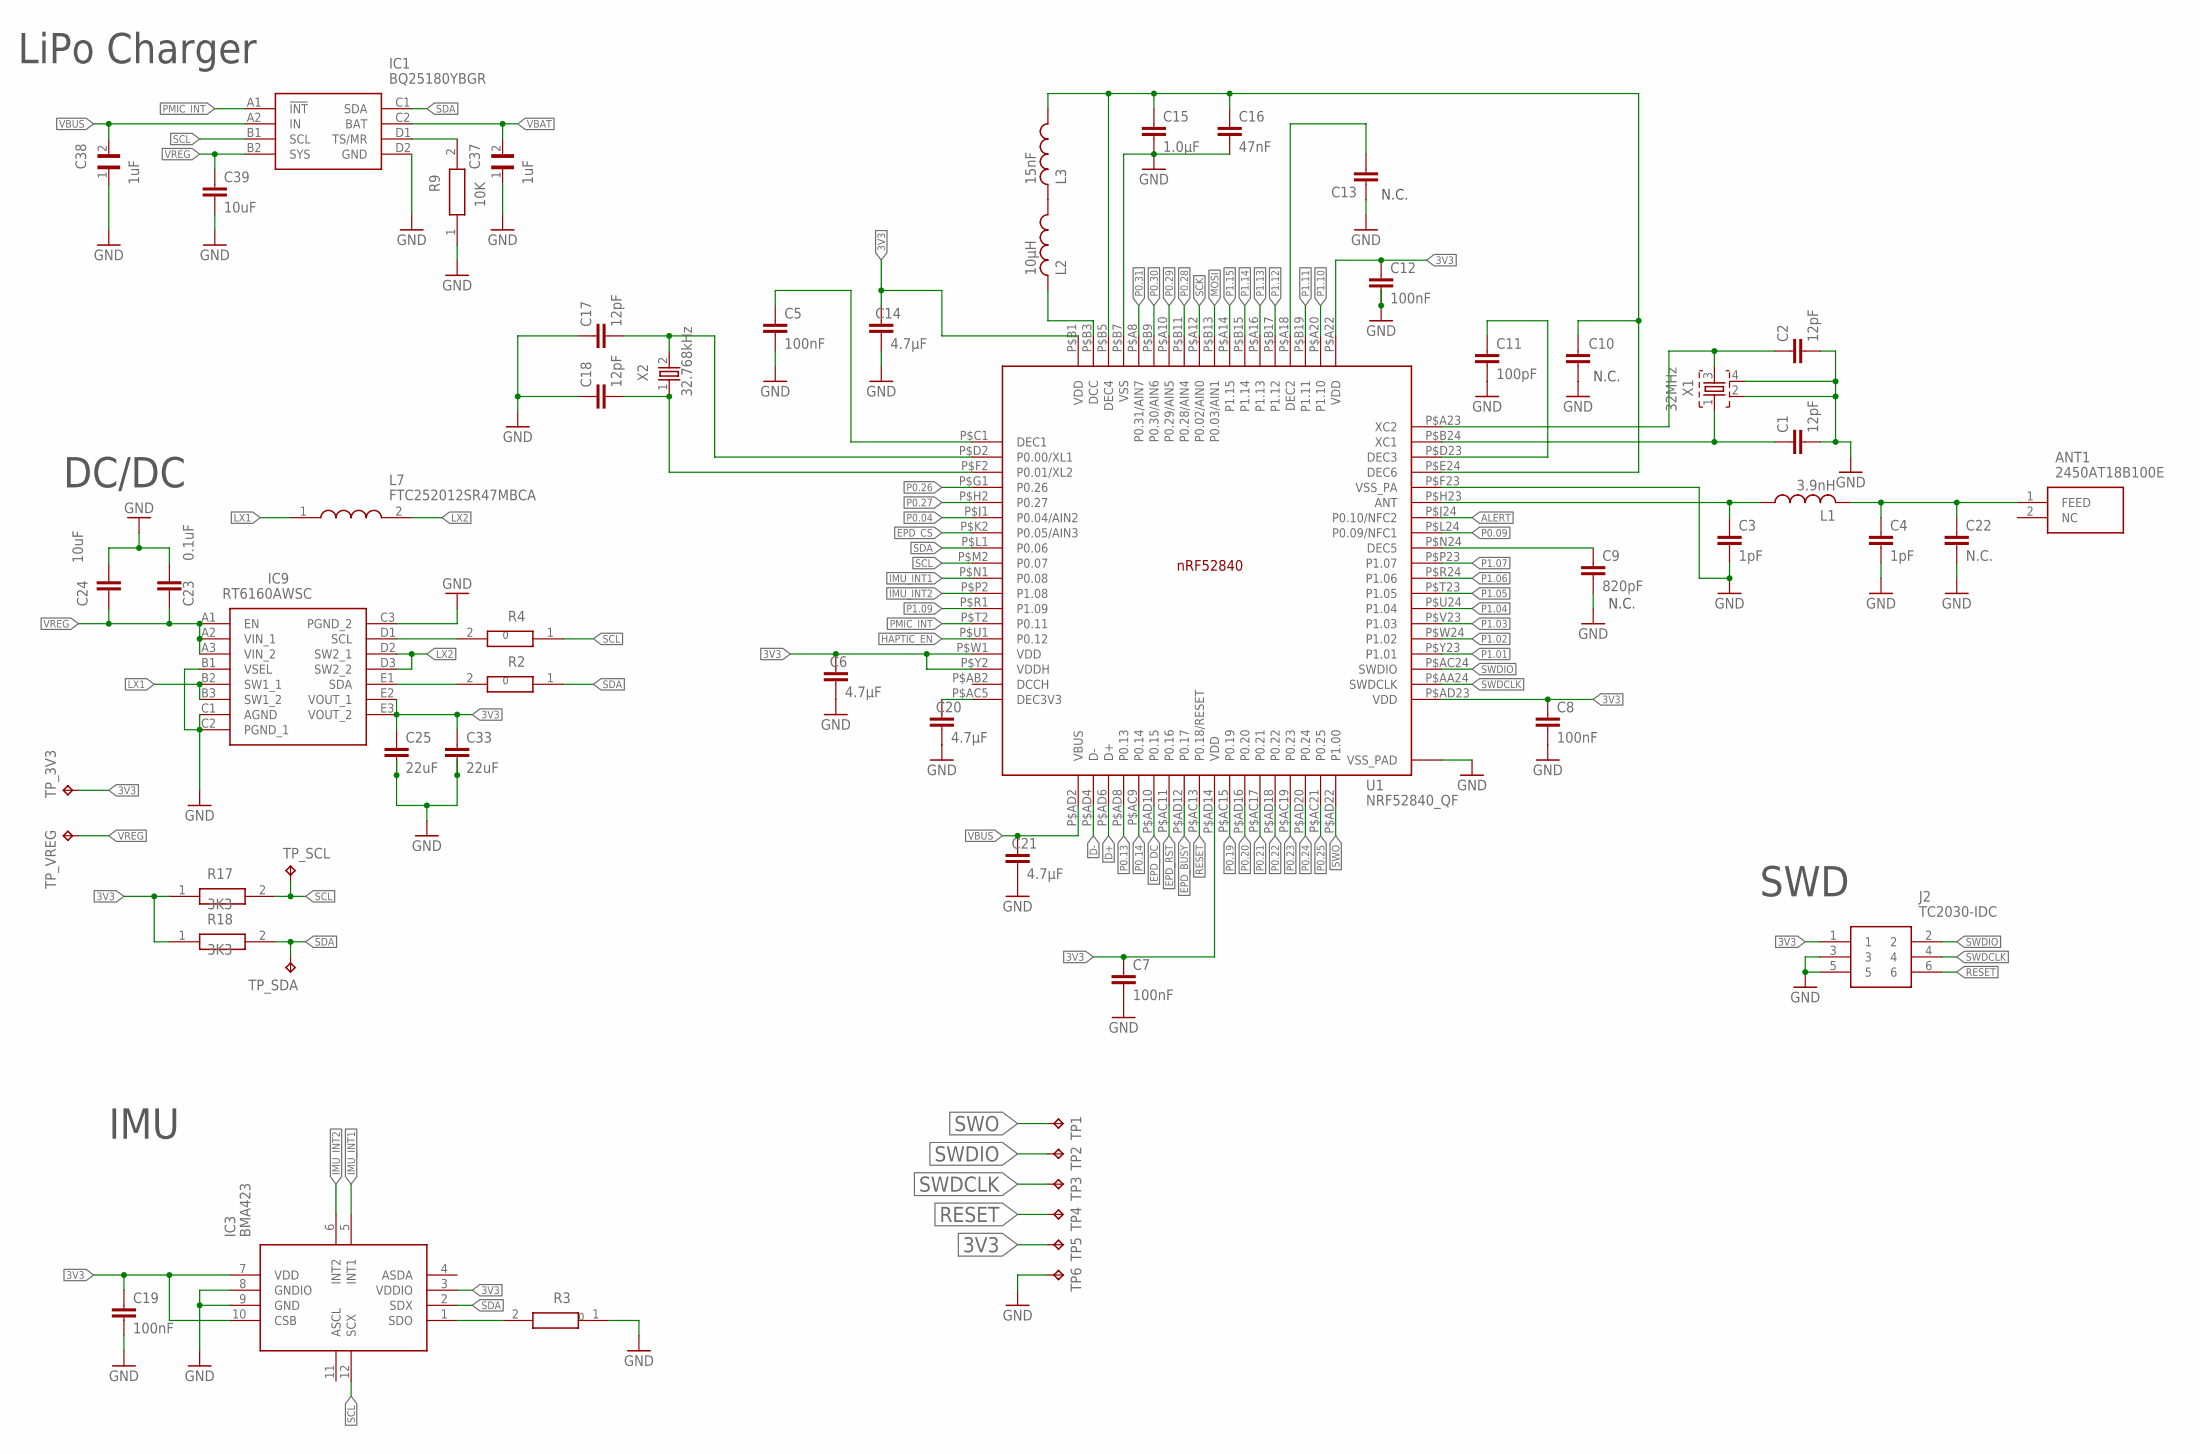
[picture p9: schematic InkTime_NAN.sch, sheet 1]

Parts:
ANT1: 2450AT18B100E; 2450AT18B100E_ANTC3216X140N
C1, C2, C17, C18: 12pF; NORDIC_NRF_3_RESC0201_L
C3, C4: 1pF; NORDIC_NRF_3_RESC0201_L
C5, C7, C8, C12, C19: 100nF; NORDIC_NRF_3_RESC0201_L
C6, C14, C20, C21: 4.7µF; NORDIC_NRF_3_RESC0402_L
C9: 820pF; NORDIC_NRF_3_RESC0201_L
C10, C13: NORDIC_NRF_3_CAPACITOR_0201_L; NORDIC_NRF_3_RESC0201_L
C11: 100pF; NORDIC_NRF_3_RESC0201_L
C15: 1.0µF; NORDIC_NRF_3_RESC0402_L
C16: 47nF; NORDIC_NRF_3_RESC0201_L
C22: N.C.; NORDIC_NRF_3_RESC0201_L
C23: 0.1uF; NORDIC_NRF_3_RESC0201_L
C24, C39: 10uF; NORDIC_NRF_3_RESC0402_L
C25, C33: 22uF; NORDIC_NRF_3_RESC0402_L
C37, C38: 1uF; GRM011R60J152KE01L_2_CAPC0201X13N
IC1: BQ25180YBGR; BQ25180YBGR_BGA8C40P2X4_100X155X50
IC3: BMA423; BMA423_BMA423
IC9: RT6160AWSC; RT6160AWSC_BGA15C40P3X5_140X230X60
J2: TC2030-IDC; TC2030-IDC_TC2030IDC
L1: 3.9nH; NORDIC_NRF_2_RESC0402_L
L2: 10µH; NORDIC_NRF_2_RESC0402_L
L3: 15nF; NORDIC_NRF_2_RESC0402_L
L7: FTC252012SR47MBCA; MLP2016SR47MT0S1_INDC2016X100N
R2, R3, R4: CPF0201D7K68C1_CPF0201D7K68C1; CPF0201D7K68C1_0201
R9: 10K; CPF0201D7K68C1_0201
R17, R18: 3K3; CPF0201D7K68C1_0201
TP1, TP2, TP3, TP4, TP5, TP6: HECTOR_WATCH_1_TPTP20R; HECTOR_WATCH_1_TP20R
TP_3V3: HECTOR_WATCH_1_TPTP20R; HECTOR_WATCH_1_TP20R
TP_SCL: HECTOR_WATCH_1_TPTP20R; HECTOR_WATCH_1_TP20R
TP_SDA: HECTOR_WATCH_1_TPTP20R; HECTOR_WATCH_1_TP20R
TP_VREG: HECTOR_WATCH_1_TPTP20R; HECTOR_WATCH_1_TP20R
U1: NRF52840_QF; NORDIC_NRF_4_AQFN50P700X700X85_HS-74N
X1: 32MHz; NORDIC_NRF_BT-XTAL_2016_N
X2: 32.768kHz; NORDIC_NRF_1_XTAL_3215_N

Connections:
3V3: C6.1, C7.1, C8.1, C12.1, C14.1, C19.1, C25.1, C33.1, IC3.3 (VDDIO), IC3.7 (VDD), IC3.10 (CSB), IC9.E2 (VOUT_1), IC9.E3 (VOUT_2), J2.1, R17.1, R18.1, TP5.TP, TP_3V3.TP, U1.P$A22 (VDD), U1.P$AD14 (VDD), U1.P$AD23 (VDD), U1.P$B1 (VDD), U1.P$W1 (VDD), U1.P$Y2 (VDDH); also elsewhere on the board
ALERT: U1.P$J24 (P0.10/NFC2); also elsewhere on the board
D+: U1.P$AD6 (D+); also elsewhere on the board
D-: U1.P$AD4 (D-); also elsewhere on the board
EPD_BUSY: U1.P$AD12 (P0.17); also elsewhere on the board
EPD_CS: U1.P$K2 (P0.05/AIN3); also elsewhere on the board
EPD_DC: U1.P$AD10 (P0.15); also elsewhere on the board
EPD_RST: U1.P$AC11 (P0.16); also elsewhere on the board
GND: C1.2, C2.2, C3.2, C4.2, C5.2, C6.2, C7.2, C8.2, C9.2, C10.1, C11.2, C12.2, C13.1, C14.2, C15.2, C16.2, C17.1, C18.1, C19.2, C20.2, C21.2, C22.2, C23.1, C24.1, C25.2, C33.2, C37.1, C38.1, C39.2, IC1.D2 (GND), IC3.8 (GNDIO), IC3.9 (GND), IC9.B1 (VSEL), IC9.C1 (AGND), IC9.C2 (PGND_1), IC9.C3 (PGND_2), J2.3, J2.5, R3.1, R9.1, TP6.TP, U1.P$74 (VSS_PAD), U1.P$75 (VSS_PAD), U1.P$76 (VSS_PAD), U1.P$77 (VSS_PAD), U1.P$78 (VSS_PAD), U1.P$79 (VSS_PAD), U1.P$80 (VSS_PAD), U1.P$81 (VSS_PAD), U1.P$82 (VSS_PAD), U1.P$83 (VSS_PAD), U1.P$84 (VSS_PAD), U1.P$85 (VSS_PAD), U1.P$86 (VSS_PAD), U1.P$87 (VSS_PAD), U1.P$88 (VSS_PAD), U1.P$89 (VSS_PAD), U1.P$90 (VSS_PAD), U1.P$B7 (VSS), U1.P$F23 (VSS_PA), X1.2, X1.4; also elsewhere on the board
HAPTIC_EN: U1.P$U1 (P0.12); also elsewhere on the board
IMU_INT1: IC3.5 (INT1), U1.P$N1 (P0.08)
IMU_INT2: IC3.6 (INT2), U1.P$P2 (P1.08)
LX1: IC9.B2 (SW1_1), IC9.B3 (SW1_2), L7.1
LX2: IC9.D2 (SW2_1), IC9.D3 (SW2_2), L7.2
MOSI: U1.P$B13 (P0.03/AIN1); also elsewhere on the board
unnamed: C5.1, U1.P$C1 (DEC1)
unnamed: C9.1, U1.P$N24 (DEC5)
unnamed: C11.1, U1.P$D23 (DEC3)
unnamed: IC9.D1 (SCL), R4.2
unnamed: C17.2, U1.P$D2 (P0.00/XL1), X2.2
unnamed: C18.2, U1.P$F2 (P0.01/XL2), X2.1
unnamed: C3.1, L1.1, U1.P$H23 (ANT)
unnamed: ANT1.1 (FEED), C4.1, C22.1, L1.2
unnamed: C10.2, C15.1, C16.1, L3.1, U1.P$B5 (DEC4), U1.P$E24 (DEC6)
unnamed: C2.1, U1.P$A23 (XC2), X1.3
unnamed: C1.1, U1.P$B24 (XC1), X1.1
unnamed: L2.1, L3.2
unnamed: L2.2, U1.P$B3 (DCC)
unnamed: C13.2, U1.P$A18 (DEC2)
unnamed: IC3.1 (SDO), R3.2
unnamed: C20.1, U1.P$AC5 (DEC3V3)
unnamed: IC9.E1 (SDA), R2.2
unnamed: IC1.D1 (TS/MR), R9.2
P0.04: U1.P$J1 (P0.04/AIN2)
P0.09: U1.P$L24 (P0.09/NFC1)
P0.13: U1.P$AD8 (P0.13); also elsewhere on the board
P0.14: U1.P$AC9 (P0.14); also elsewhere on the board
P0.19: U1.P$AC15 (P0.19)
P0.20: U1.P$AD16 (P0.20)
P0.21: U1.P$AC17 (P0.21)
P0.22: U1.P$AD18 (P0.22)
P0.23: U1.P$AC19 (P0.23)
P0.24: U1.P$AD20 (P0.24)
P0.25: U1.P$AC21 (P0.25)
P0.26: U1.P$G1 (P0.26)
P0.27: U1.P$H2 (P0.27)
P0.28: U1.P$B11 (P0.28/AIN4)
P0.29: U1.P$A10 (P0.29/AIN5)
P0.30: U1.P$B9 (P0.30/AIN6)
P0.31: U1.P$A8 (P0.31/AIN7)
P1.01: U1.P$Y23 (P1.01); also elsewhere on the board
P1.02: U1.P$W24 (P1.02); also elsewhere on the board
P1.03: U1.P$V23 (P1.03)
P1.04: U1.P$U24 (P1.04)
P1.05: U1.P$T23 (P1.05)
P1.06: U1.P$R24 (P1.06)
P1.07: U1.P$P23 (P1.07)
P1.09: U1.P$R1 (P1.09)
P1.10: U1.P$A20 (P1.10)
P1.11: U1.P$B19 (P1.11)
P1.12: U1.P$B17 (P1.12)
P1.13: U1.P$A16 (P1.13)
P1.14: U1.P$B15 (P1.14)
P1.15: U1.P$A14 (P1.15)
PMIC_INT: IC1.A1 (!INT), U1.P$T2 (P0.11)
RESET: J2.6, TP4.TP, U1.P$AC13 (P0.18/RESET)
SCK: U1.P$A12 (P0.02/AIN0); also elsewhere on the board
SCL: IC1.B1 (SCL), IC3.12 (SCX), R4.1, R17.2, TP_SCL.TP, U1.P$M2 (P0.07); also elsewhere on the board
SDA: IC1.C1 (SDA), IC3.2 (SDX), R2.1, R18.2, TP_SDA.TP, U1.P$L1 (P0.06); also elsewhere on the board
SWDCLK: J2.4, TP3.TP, U1.P$AA24 (SWDCLK)
SWDIO: J2.2, TP2.TP, U1.P$AC24 (SWDIO)
SWO: TP1.TP, U1.P$AD22 (P1.00)
VBAT: C37.2, IC1.C2 (BAT); also elsewhere on the board
VBUS: C21.1, C38.2, IC1.A2 (IN), U1.P$AD2 (VBUS); also elsewhere on the board
VREG: C23.2, C24.2, C39.1, IC1.B2 (SYS), IC9.A1 (EN), IC9.A2 (VIN_1), IC9.A3 (VIN_2), TP_VREG.TP

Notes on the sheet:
N.C.
SWD
IMU
DC/DC
LiPo Charger

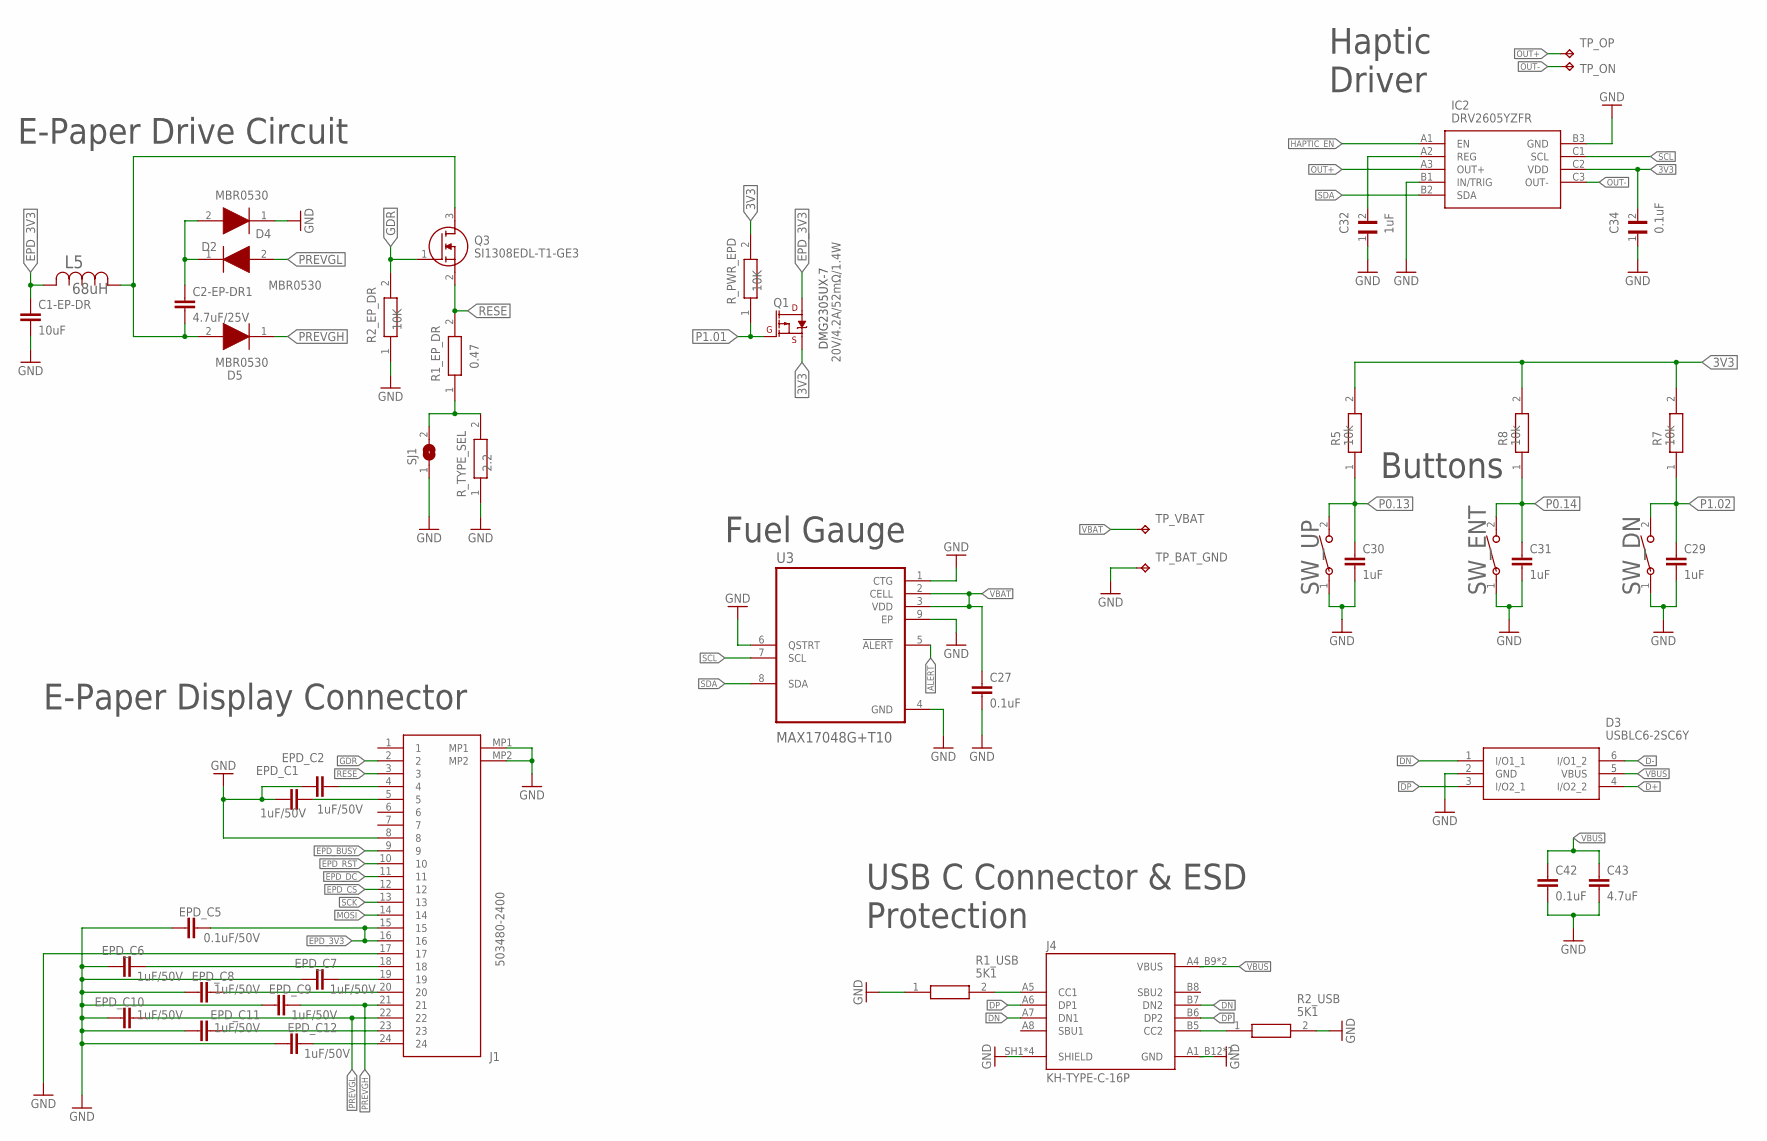
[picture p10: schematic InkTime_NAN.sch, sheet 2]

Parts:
C1-EP-DR: 10uF; NORDIC_NRF_3_RESC0402_L
C2-EP-DR1: 4.7uF/25V; NORDIC_NRF_3_RESC0402_L
C27, C42: 0.1uF; NORDIC_NRF_3_RESC0201_L
C29, C30, C31: 1uF; NORDIC_NRF_3_RESC0402_L
C32: 1uF; GRM011R60J152KE01L_2_CAPC0201X13N
C34: 0.1uF; GRM011R60J152KE01L_2_CAPC0201X13N
C43: 4.7uF; NORDIC_NRF_3_RESC0402_L
D2, D4, D5: MBR0530; ESP32_C6_LIBRARY_5_SOD3716X135N
D3: USBLC6-2SC6Y; ESP32_C6_LIBRARY_3_SOT95P280X145-6N
EPD_C1, EPD_C2, EPD_C6, EPD_C7, EPD_C8, EPD_C9, EPD_C10, EPD_C11, EPD_C12: 1uF/50V; NORDIC_NRF_3_RESC0402_L
EPD_C5: 0.1uF/50V; NORDIC_NRF_3_RESC0201_L
IC2: DRV2605YZFR; DRV2605YZFR_BGA9C50P3X3_144X144X62
J1: 503480-2400; 503480-2400_5034802400
J4: KH-TYPE-C-16P; KH-TYPE-C-16P_KINGHELM_KH-TYPE-C-16P
L5: 68uH; ESP32_C6_LIBRARY_2_IND_4828-WE-TPC_WRE
Q1: 20V/4.2A/52mΩ/1.4W; ESP32_C6_LIBRARY_4_ESP32_C6_LIBRARY_4_ESP32_C6_LIBRARY_4_ES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
Q3: SI1308EDL-T1-GE3; ESP32_C6_LIBRARY_6_SOT65P210X110-3N
R1_EP_DR: 0.47; CPF0201D7K68C1_0201
R1_USB, R2_USB: 5K1; ERA-1AEB3401C_0201
R2_EP_DR: 10K; CPF0201D7K68C1_0201
R5, R7, R8: 10k; CPF0201D7K68C1_0201
R_PWR_EPD: 10K; CPF0201D7K68C1_0201
R_TYPE_SEL: 2.2; CPF0201D7K68C1_0201
SJ1: ESP32_C6_LIBRARY_7_JUMPER_SJ
SW_DN: 2025-10-22_07-23-44_LIBRARY_EVP-AKE31ASW_EVP-AKE3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; 2025-10-22_07-23-44_LIBRARY_SW_EVP-AKE31A_PAN
SW_ENT: SW_ENT; 2025-10-22_07-23-44_LIBRARY_SW_EVP-AKE31A_PAN
SW_UP: 2025-10-22_07-23-44_LIBRARY_EVP-AKE31ASW_EVP-AKE3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; 2025-10-22_07-23-44_LIBRARY_SW_EVP-AKE31A_PAN
TP_BAT_GND: HECTOR_WATCH_1_TPTP20R; HECTOR_WATCH_1_TP20R
TP_ON: HECTOR_WATCH_1_TPTP20R; HECTOR_WATCH_1_TP20R
TP_OP: HECTOR_WATCH_1_TPTP20R; HECTOR_WATCH_1_TP20R
TP_VBAT: HECTOR_WATCH_1_TPTP20R; HECTOR_WATCH_1_TP20R
U3: MAX17048G+T10; ESP32_C6_LIBRARY_SON50P200X200X80-9N

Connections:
3V3: C34.2, IC2.C2 (VDD), Q1.2 (S), R5.2, R7.2, R8.2, R_PWR_EPD.2; also elsewhere on the board
ALERT: U3.5 (!ALERT); also elsewhere on the board
D+: D3.4 (I/O2_2); also elsewhere on the board
D-: D3.6 (I/O1_2); also elsewhere on the board
DN: D3.1 (I/O1_1), J4.A7 (DN1), J4.B7 (DN2)
DP: D3.3 (I/O2_1), J4.A6 (DP1), J4.B6 (DP2)
EPD_3V3: C1-EP-DR.1, EPD_C5.2, J1.15, J1.16, L5.2, Q1.3 (D)
EPD_BUSY: J1.9; also elsewhere on the board
EPD_CS: J1.12; also elsewhere on the board
EPD_DC: J1.11; also elsewhere on the board
EPD_RST: J1.10; also elsewhere on the board
GDR: J1.2, Q3.1 (G), R2_EP_DR.2
GND: C1-EP-DR.2, C27.2, C29.2, C30.2, C31.2, C32.1, C34.1, C42.2, C43.2, D2.1 (K), D3.2 (GND), EPD_C1.1, EPD_C2.1, EPD_C5.1, EPD_C6.1, EPD_C7.1, EPD_C8.1, EPD_C9.1, EPD_C10.1, EPD_C11.1, EPD_C12.1, IC2.B1 (IN/TRIG), IC2.B3 (GND), J1.8, J1.17, J1.MP1, J1.MP2, J4.A1_B12 (GND), J4.A12_B1 (GND), J4.SH1 (SHIELD), J4.SH2 (SHIELD), J4.SH3 (SHIELD), J4.SH4 (SHIELD), R1_USB.1, R2_EP_DR.1, R2_USB.2, R_TYPE_SEL.1, SJ1.1, SW_DN.1, SW_ENT.1, SW_UP.1, TP_BAT_GND.TP, U3.1 (CTG), U3.4 (GND), U3.6 (QSTRT), U3.9 (EP); also elsewhere on the board
HAPTIC_EN: IC2.A1 (EN); also elsewhere on the board
MOSI: J1.14; also elsewhere on the board
unnamed: C2-EP-DR1.2, D5.2 (A), L5.1, Q3.3 (D)
unnamed: EPD_C8.2, J1.20
unnamed: C2-EP-DR1.1, D2.2 (A), D4.1 (K)
unnamed: EPD_C2.2, J1.4
unnamed: R1_EP_DR.1, R_TYPE_SEL.2, SJ1.2
unnamed: EPD_C1.2, J1.5
unnamed: C32.2, IC2.A2 (REG)
unnamed: J4.B5 (CC2), R2_USB.1
unnamed: J4.A5 (CC1), R1_USB.2
unnamed: EPD_C7.2, J1.19
unnamed: EPD_C6.2, J1.18
unnamed: EPD_C11.2, J1.23
unnamed: EPD_C12.2, J1.24
OUT+: IC2.A3 (OUT+), TP_OP.TP
OUT-: IC2.C3 (OUT-), TP_ON.TP
P0.13: C30.1, R5.1, SW_UP.2; also elsewhere on the board
P0.14: C31.1, R8.1, SW_ENT.2; also elsewhere on the board
P1.01: Q1.1 (G), R_PWR_EPD.1; also elsewhere on the board
P1.02: C29.1, R7.1, SW_DN.2; also elsewhere on the board
PREVGH: D5.1 (K), EPD_C9.2, J1.21
PREVGL: D4.2 (A), EPD_C10.2, J1.22
RESE: J1.3, Q3.2 (S), R1_EP_DR.2
SCK: J1.13; also elsewhere on the board
SCL: IC2.C1 (SCL), U3.7 (SCL); also elsewhere on the board
SDA: IC2.B2 (SDA), U3.8 (SDA); also elsewhere on the board
VBAT: C27.1, TP_VBAT.TP, U3.2 (CELL), U3.3 (VDD); also elsewhere on the board
VBUS: C42.1, C43.1, D3.5 (VBUS), J4.A4_B9 (VBUS), J4.A9_B4 (VBUS); also elsewhere on the board

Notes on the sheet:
DMG2305UX-7
E-Paper Drive Circuit
Haptic Driver
Buttons
Fuel Gauge
E-Paper Display Connector
USB C Connector & ESD Protection

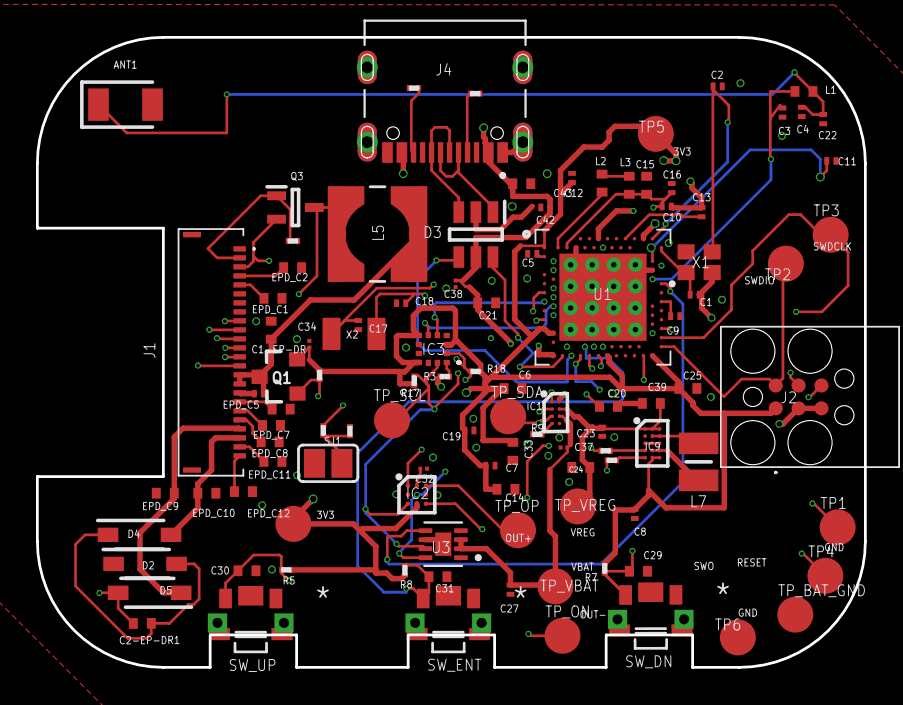
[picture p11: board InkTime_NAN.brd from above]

Board: 4 copper layers, 46.0 x 35.0 mm, 105 parts (0 on the bottom side), 70 nets.

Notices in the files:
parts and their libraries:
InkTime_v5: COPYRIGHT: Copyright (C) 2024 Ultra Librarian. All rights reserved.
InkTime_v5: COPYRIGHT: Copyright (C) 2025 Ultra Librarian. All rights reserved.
